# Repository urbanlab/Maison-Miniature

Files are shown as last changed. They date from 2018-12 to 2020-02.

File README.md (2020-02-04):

# Maison-Miniature

La Maison Miniature est un outil pour échanger avec les seniors sur la thématique du bien vivre chez soi dans le cadre d’ateliers collectifs de prévention. Cet objet physique facilite l’expression des bénéficiaires sur le sujet de l’adaptation du domicile. Il a été conçu et testé avec un ergothérapeute. Elle a été pensée pour les associations d’éducation et de prévention à la santé, les caisses de retraites, les mutuelles, et tous les professionnels de la prévention.

Maquette d’un habitat, elle reproduit à échelle réduite des espaces et du mobilier. Elle permet de mettre en scène différents aménagements, de reproduire les situations à risque et illustrer les bonnes pratiques. 

Les sources et les méthodologies du projet sont diffusées par la métropole de Lyon sous licenses ouvertes 
- AGPLV3 pour les plans
- CCBySA pour les documentations et plans

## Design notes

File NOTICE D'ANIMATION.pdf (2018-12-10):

# LA MAISON MINIATURE

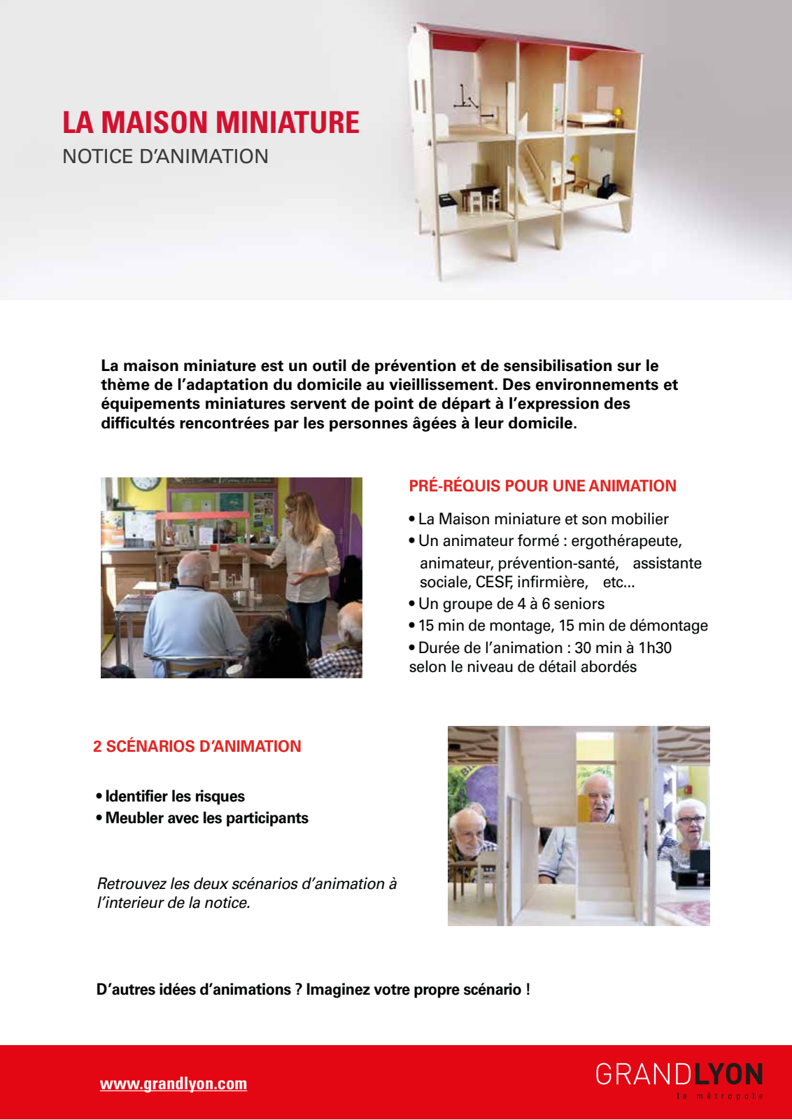
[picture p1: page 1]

### NOTICE D’ANIMATION

La maison miniature est un outil de prévention et de sensibilisation sur le thème de l’adaptation du domicile au vieillissement. Des environnements et équipements miniatures servent de point de départ à l’expression des difficultés rencontrées par les personnes âgées à leur domicile.

PRÉ-RÉQUIS POUR UNE ANIMATION

### 2 SCÉNARIOS D’ANIMATION

- La Maison miniature et son mobilier
- Un animateur formé : ergothérapeute, animateur, prévention-santé, assistante sociale, CESF, infirmière, etc...
- Un groupe de 4 à 6 seniors
- 15 min de montage, 15 min de démontage
- Durée de l’animation : 30 min à 1h30 selon le niveau de détail abordés
- Identifier les risques
- Meubler avec les participants

Retrouvez les deux scénarios d’animation à l’interieur de la notice.

D’autres idées d’animations ? Imaginez votre propre scénario !

www.grandlyon.com

# SCÉNARIO 1

### IDENTIFIER LES RISQUES

Avant le début de l’atelier, organiser les pièces de la maison avec le mobilier nécessaire en créant volontairement des zones à risque : tapis plissé, fils qui traînent, manque d’éclairage, encombrement, …

L’environnement de la maison sert alors de point de départ à l’expression des participants.

Échange pièces par pièce :

- L’animateur part d’une pièce (la cuisine par exemple) et invite les participants à identifier les éventuels dangers ou matériels inadaptés visibles dans la maison.

Partir de situations vécues :

- L’animateur invite les participants à partager leurs expériences sur des
situations | problématiques | qu’ils
peuvent rencontrer dans leur domicile.

### 2 possibilités :

Au fil de la discussion les participants et l’animateur échangent sur les solutions possibles.

L’animateur vient enrichir le dialogue avec des solutions techniques (conseils pratiques, aides techniques, aménagement entraînant des travaux) afin de rendre le logement sûr, confortable et sécurisé

Il modélise ses propos dans la maison grâce aux « éléments adaptés », afin de pouvoir visualiser l’environnement avec les solutions d’aménagements proposées.

1

2

4

5

6

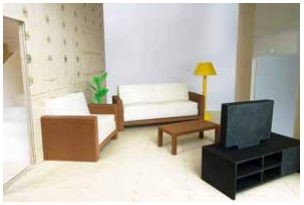
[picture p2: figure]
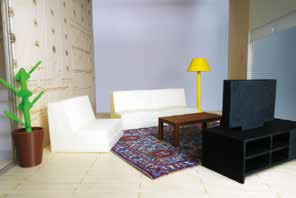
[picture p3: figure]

Avant : non adapté | Après: adapté

Notice technique Commencer la séance avec la maison vide de tout mobilier. Mettre à disposition des participants l’ensemble du mobilier disponible.

Demander aux participants d’aménager l’environnement comme ils le
souhaitent avec le mobilier mis à disposition

Plusieurs consignes sont possibles :

- Réaliser l’aménagement le plus adapté possible
- Réaliser l’aménagement le moins adapté possible
- Représenter les problématiques qu’ils rencontrent chez eux

Le temps d’aménagement permet à l’animateur de débuter les échanges avec les participants sur les éléments qui peuvent entraîner des difficultés dans la vie quotidienne ainsi que sur les éléments facilitateurs ou adaptés.

L’animateur vient enrichir le dialogue avec des solutions techniques (conseils pratiques, aides techniques, aménagement entraînant des travaux) afin de rendre le logement sûr, confortable et sécurisé

L’animateur modélise ses propos dans la maison grâce aux « éléments adaptés », afin de permettre de visualiser l’environnement avec les solutions d’aménagements proposées.

1

2

3

4

5

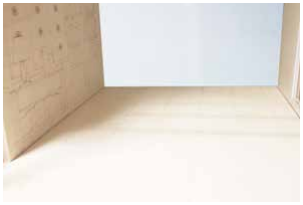
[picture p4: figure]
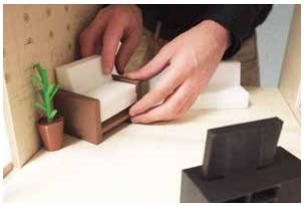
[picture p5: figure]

Avant : pièce vide | Pendant : pièce en cours de montage

# SCÉNARIO 2

### MEUBLER AVEC LES PARTICIPANTS

La maison miniature est un outil dont le développement
a été financé par la Conférence des financeurs de la prévention de la perte d’autonomie.

Elle a été imaginée avec l’expertise d’un ergothérapeute dans le contexte du projet Bien Vivre Chez Soi à la Métropole, mené par la Métropole de Lyon et Erasme.

La maquette a été conçue et développée par Youfactory
puis testée par la Métropole de Lyon et Erasme auprès de groupes de seniors.

Liens pratiques :
- https://www.grandlyon.com/
- https://www.erasme.org
- http://youfactory.co/
- https://www.cnsa.fr/
- Vidéo de présentation de l’outil : https://bit.ly/2FXnNia
- Notice de montage : https://bit.ly/2Q3kI54
- Page projet : https://www.erasme.org/La-Maison-Miniature-1
- Tous outils du projet Bien Vivre Chez Soi à La Métropole : https://www.erasme.org/#solidarite

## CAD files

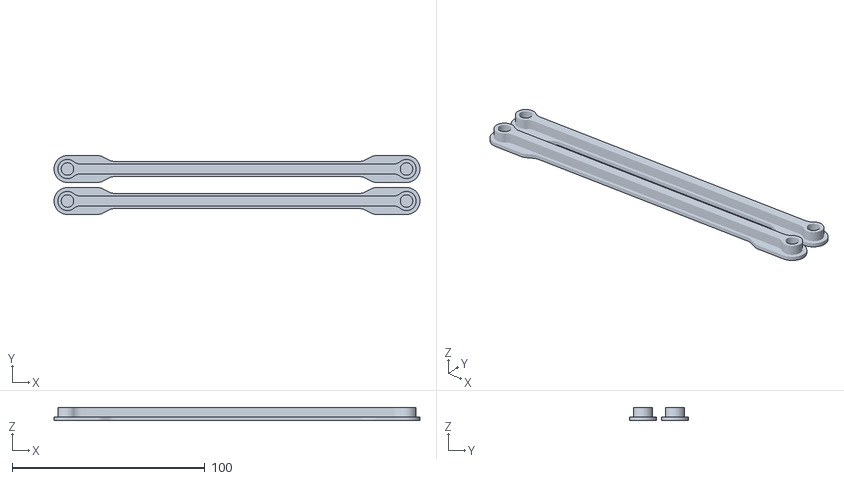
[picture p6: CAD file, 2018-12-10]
CAHIER DE PLANS/MOBILIER/IMPRESSION 3D/ESC-Main courantes.stl
190.0 x 30.6 x 7.00

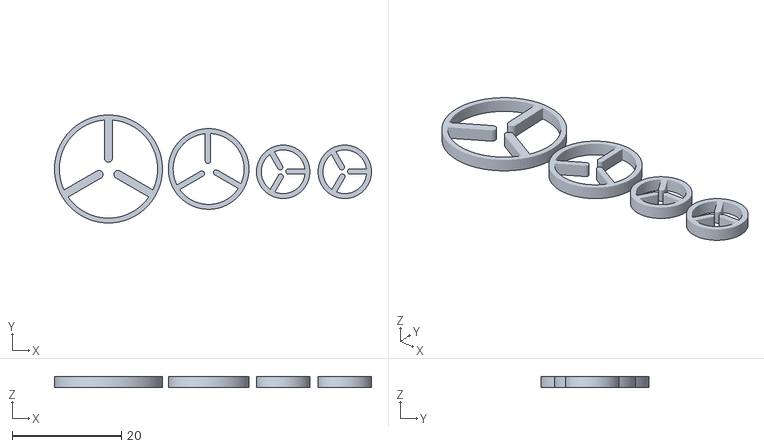
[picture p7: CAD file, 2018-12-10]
CAHIER DE PLANS/MOBILIER/IMPRESSION 3D/CUIS-Plaques gaz.stl
58.1 x 19.8 x 2.00

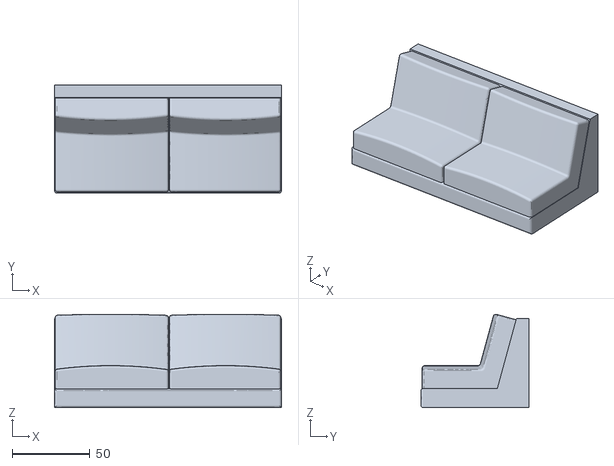
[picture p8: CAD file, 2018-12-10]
CAHIER DE PLANS/MOBILIER/IMPRESSION 3D/SAL-Canape assise.stl
146.0 x 69.7 x 60.1

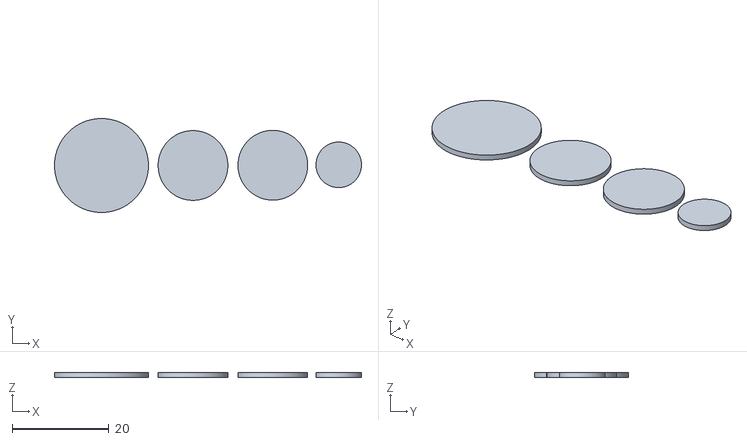
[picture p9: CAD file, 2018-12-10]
CAHIER DE PLANS/MOBILIER/IMPRESSION 3D/CUIS-Plaques vitro.stl
63.4 x 19.4 x 1

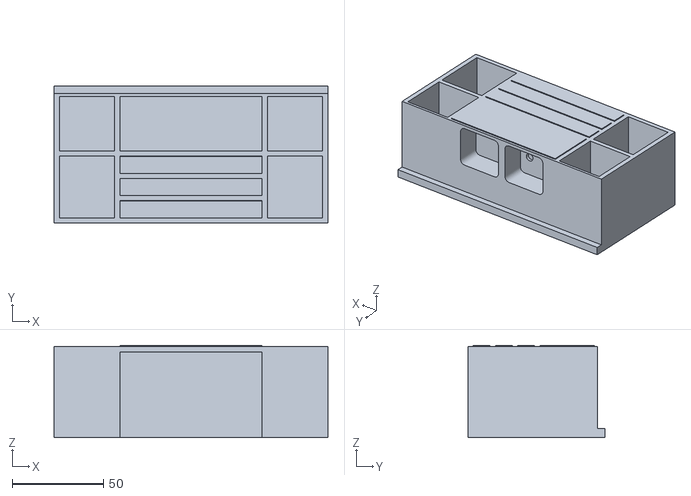
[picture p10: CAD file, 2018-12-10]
CAHIER DE PLANS/MOBILIER/IMPRESSION 3D/CUIS-Meuble evier Bot.stl
150.0 x 75.0 x 50.5

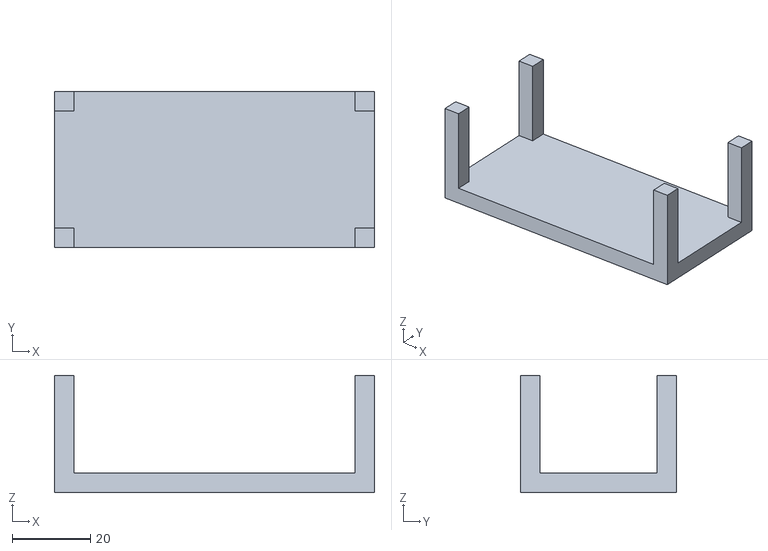
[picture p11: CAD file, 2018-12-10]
CAHIER DE PLANS/MOBILIER/IMPRESSION 3D/SAL-Table basse.stl
82.0 x 40.0 x 30.0

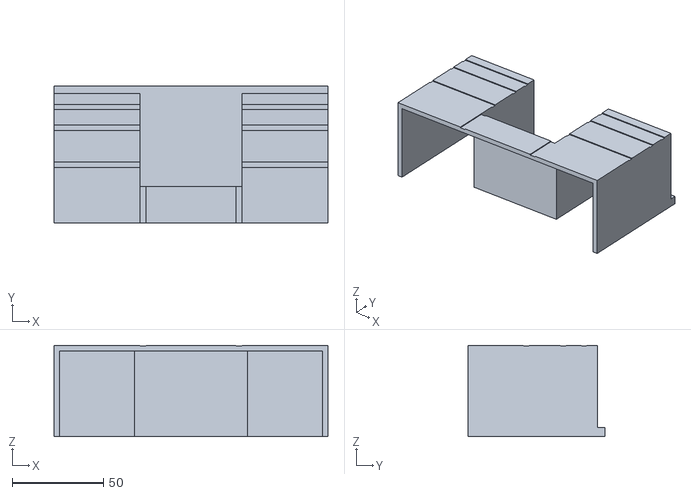
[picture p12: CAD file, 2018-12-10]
CAHIER DE PLANS/MOBILIER/IMPRESSION 3D/CUIS-Meuble cuisson Bot.stl
150.0 x 75.0 x 50.0

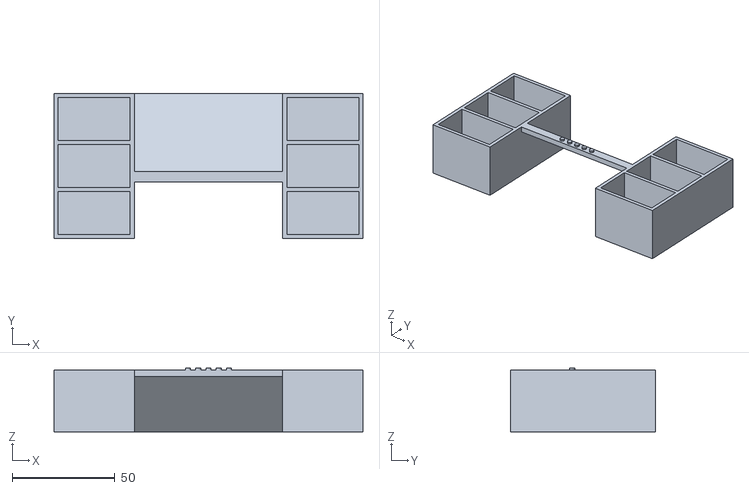
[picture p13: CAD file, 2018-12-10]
CAHIER DE PLANS/MOBILIER/IMPRESSION 3D/CUIS-Meuble cuisson Top.stl
150.0 x 70.5 x 31.0

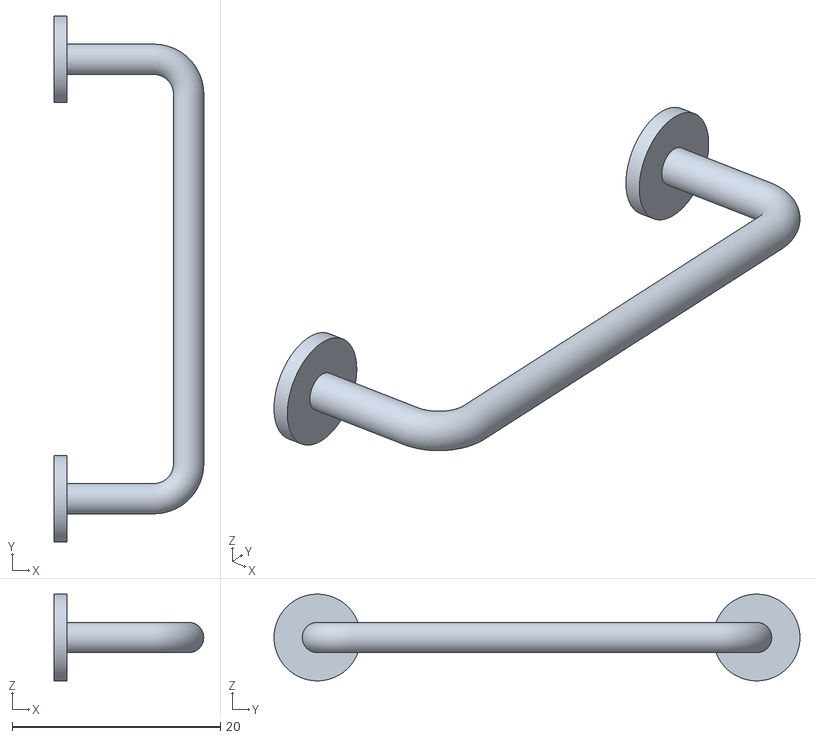
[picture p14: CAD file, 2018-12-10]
CAHIER DE PLANS/MOBILIER/IMPRESSION 3D/SDB-Douche petit barre.stl
14.4 x 50.5 x 8.33

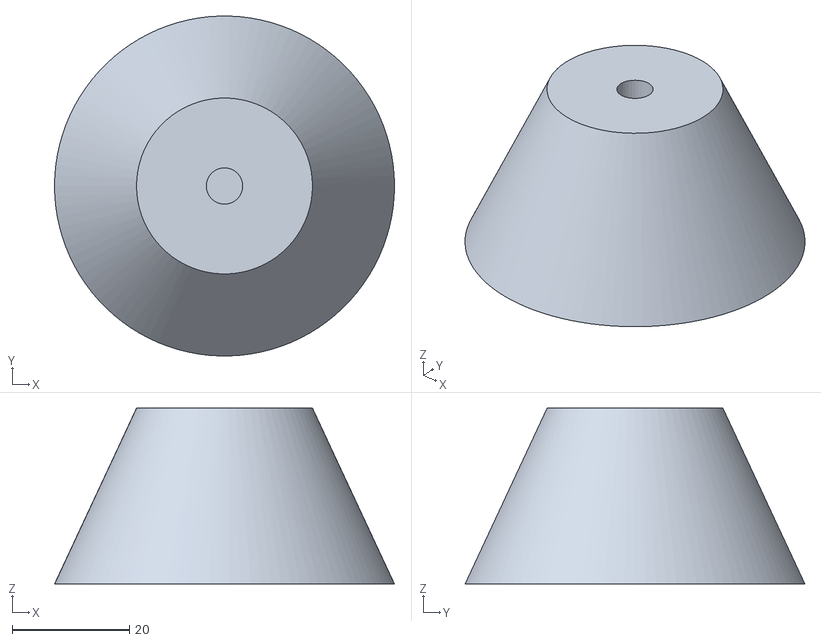
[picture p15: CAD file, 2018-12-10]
CAHIER DE PLANS/MOBILIER/IMPRESSION 3D/SAL-Plafonnier.stl
58.0 x 58.0 x 30.0

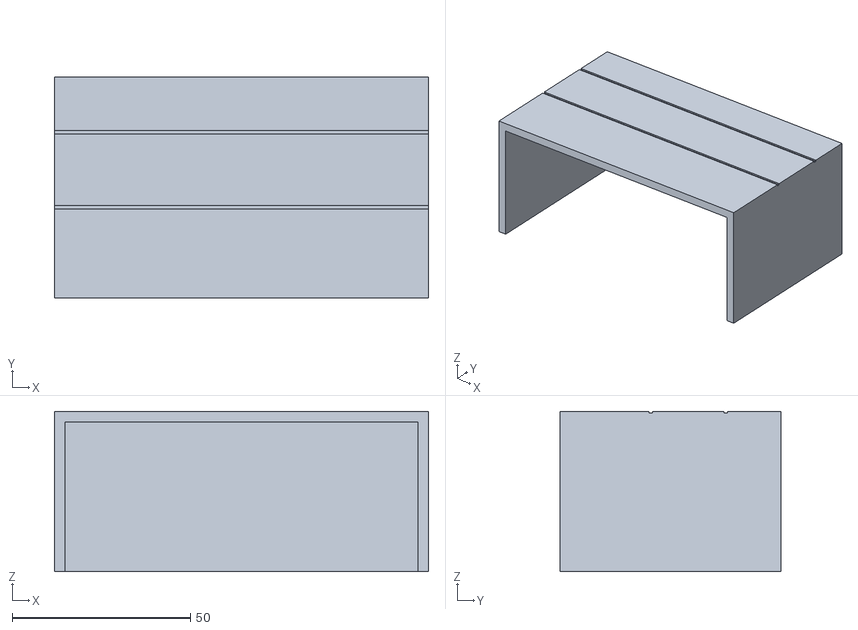
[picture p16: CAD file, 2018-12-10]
CAHIER DE PLANS/MOBILIER/IMPRESSION 3D/CHBRE-Commode.stl
105.0 x 62.0 x 45.0

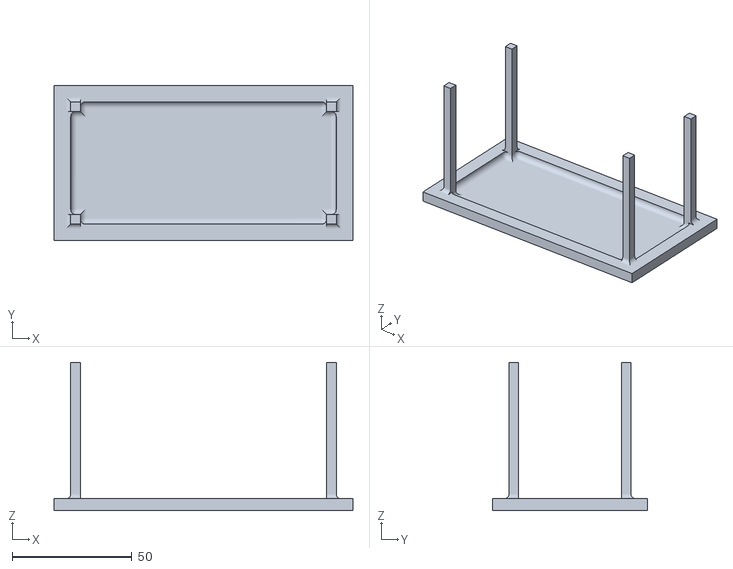
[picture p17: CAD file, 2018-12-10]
CAHIER DE PLANS/MOBILIER/IMPRESSION 3D/CUIS-Table Ö manger.stl
125.0 x 65.0 x 62.0

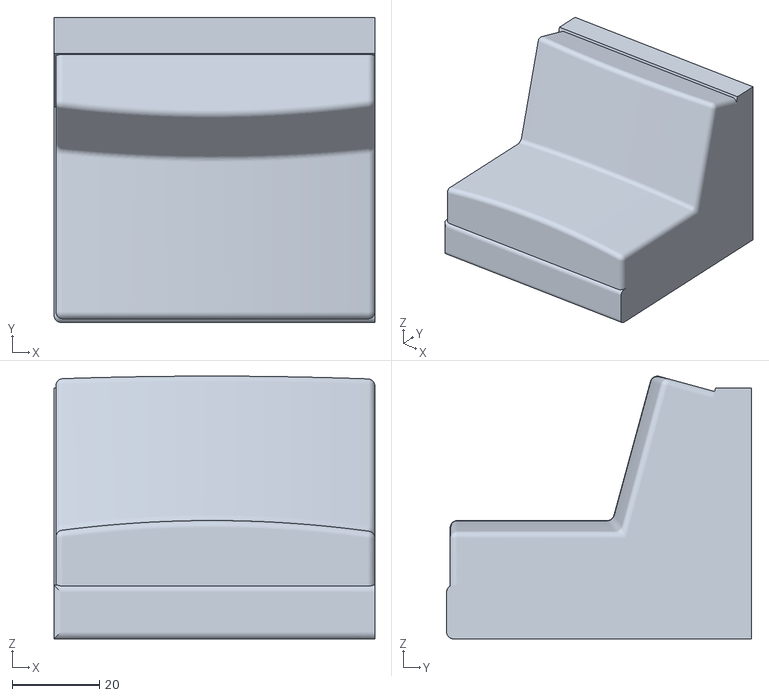
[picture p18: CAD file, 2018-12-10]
CAHIER DE PLANS/MOBILIER/IMPRESSION 3D/SAL-Fauteuil assise.stl
73.4 x 69.7 x 60.1

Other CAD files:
CAHIER DE PLANS/BOITE DE TRANSPORT/DECOUPE CNC/PLAN DE DECOUPE MOUSSE 15MM MANUEL.dwg
CAHIER DE PLANS/MURS ET PLANCHERS/CNC/FRAISAGE CNC MURS ET PLANCHERS.dwg
CAHIER DE PLANS/STRUCTURE ALUMINIUM/STRUCTURE ALUMINIUM.dwg
CAHIER DE PLANS/TOIT/CNC/DECOUPE TOIT.dwg
CAHIER DE PLANS/BOITE DE TRANSPORT/DECOUPE CNC/PLAN DE DECOUPE MOUSSE 25MM CNC.dwg
CAHIER DE PLANS/MOBILIER/IMPRESSION 3D/ATR-Cartons.stl
CAHIER DE PLANS/MOBILIER/IMPRESSION 3D/ATR-Plante.stl
CAHIER DE PLANS/MOBILIER/IMPRESSION 3D/ATR-Pot plante.stl
CAHIER DE PLANS/MOBILIER/IMPRESSION 3D/CHBRE-Lampe haute.stl
CAHIER DE PLANS/MOBILIER/IMPRESSION 3D/CHBRE-Matelas.stl
CAHIER DE PLANS/MOBILIER/IMPRESSION 3D/CHBRE-Sommier.stl
CAHIER DE PLANS/MOBILIER/IMPRESSION 3D/CHBRE-Table chevet X2.stl
CAHIER DE PLANS/MOBILIER/IMPRESSION 3D/CUIS-Bloc Vitro.stl
CAHIER DE PLANS/MOBILIER/IMPRESSION 3D/CUIS-Bloc gaziniäre.stl
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

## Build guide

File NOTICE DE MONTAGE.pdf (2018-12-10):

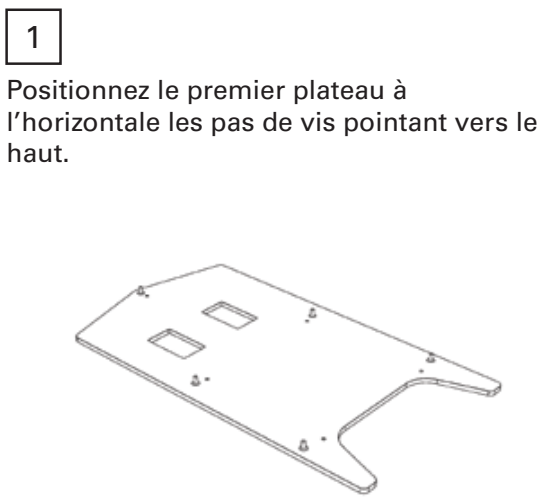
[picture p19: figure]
Positionnez le premier plateau à; haut.

l’horizontale les pas de vis pointant vers le

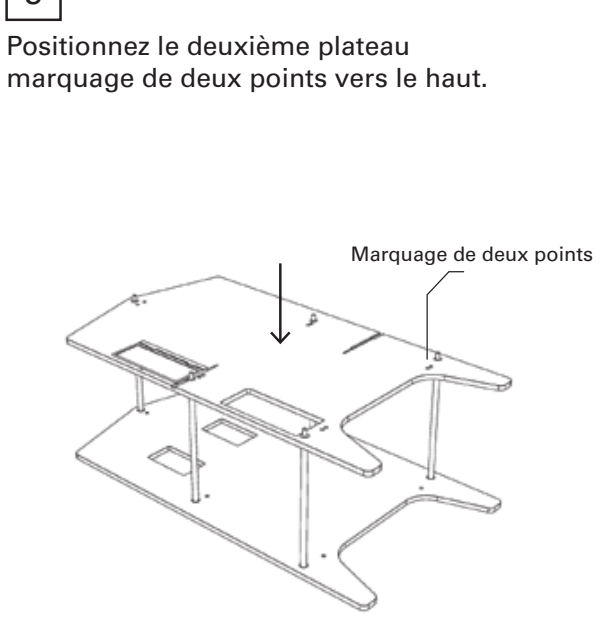
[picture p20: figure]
Positionnez le deuxième plateau marquage de deux points vers le haut.; Marquage de deux points

3

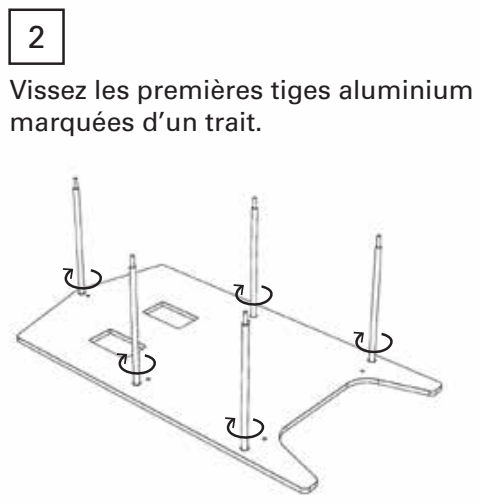
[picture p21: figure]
Vissez les premières tiges aluminium marquées d’un trait.
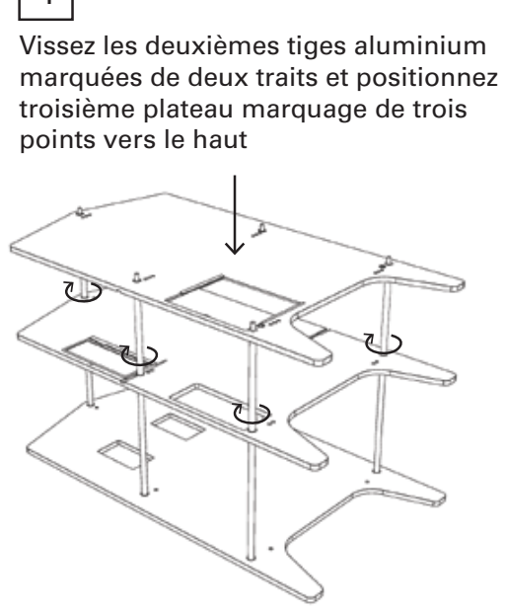
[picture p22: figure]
Vissez les deuxièmes tiges aluminium; troisième plateau marquage de trois points vers le haut

4

marquées de deux traits et positionnez le

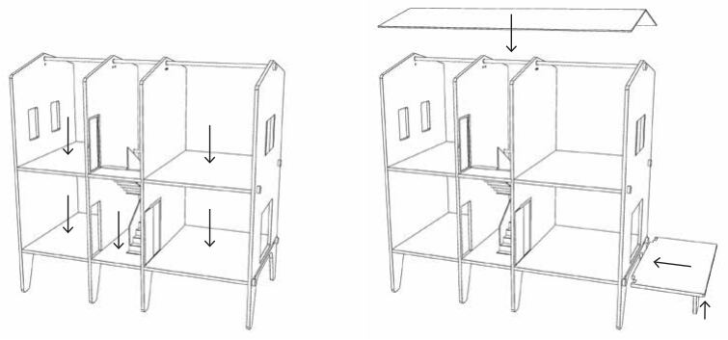
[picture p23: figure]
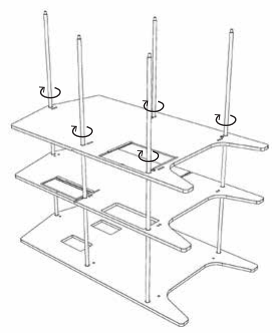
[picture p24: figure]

5

Vissez les troisièmes tiges aluminium marquées de troits traits.

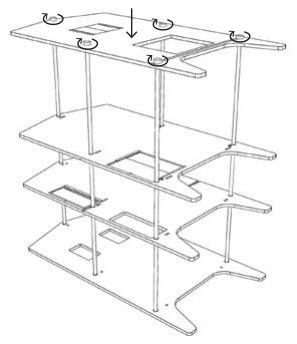
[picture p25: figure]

6

Positionnez le dernier plateau et vissez les cinq goupilles afin de solidariser l’ensemble.

7

8

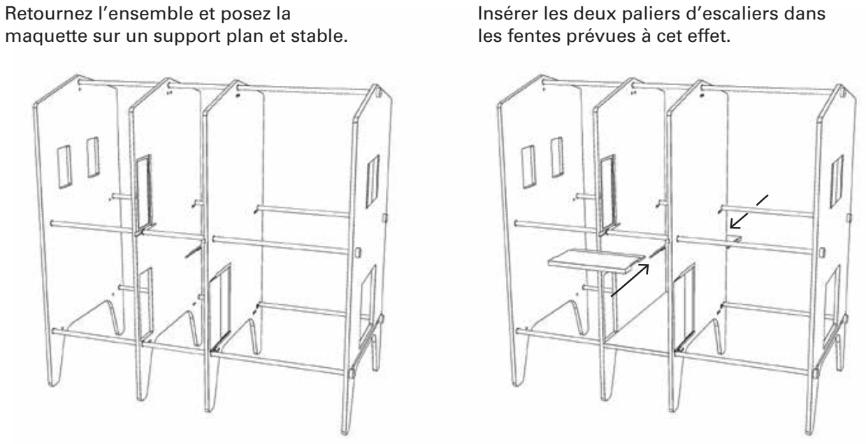
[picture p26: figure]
Retournez l’ensemble et posez la maquette sur un support plan et stable.; les fentes prévues à cet effet.

Insérer les deux paliers d’escaliers dans

9

Positionnez l’ensemble des planchers. Positionnez les deux travées d’escaliers. Elles reposent sur les deux paliers et sur le plancher central bas.

10

Positionnez le toit.
Fixez le socle du plancher de la terrasse et insérer l’ensemble dans la fente prévue sur le dernier panneau.

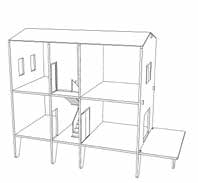
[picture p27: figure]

Votre maquette est prête à reçevoir son mobilier !

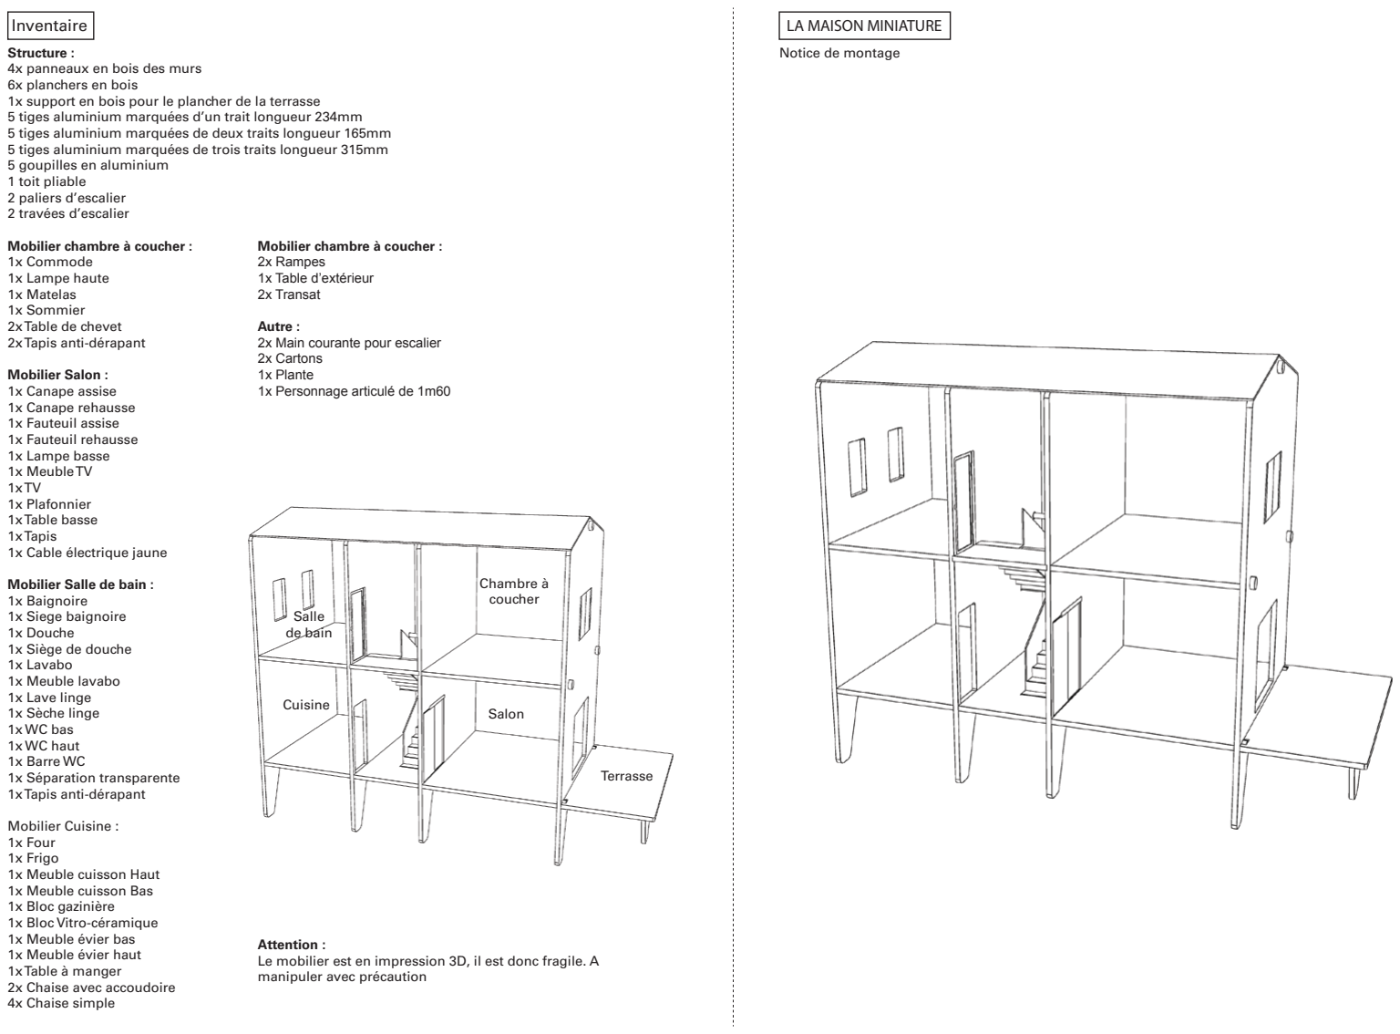
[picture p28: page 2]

Inventaire | LA MAISON MINIATURE

Structure :
4x panneaux en bois des murs
6x planchers en bois
1x support en bois pour le plancher de la terrasse
5 tiges aluminium marquées d’un trait longueur 234mm
5 tiges aluminium marquées de deux traits longueur 165mm 5 tiges aluminium marquées de trois traits longueur 315mm 5 goupilles en aluminium
1 toit pliable
2 paliers d’escalier
2 travées d’escalier

Mobilier chambre à coucher : 1x Commode
1x Lampe haute
1x Matelas
1x Sommier
2x Table de chevet
2x Tapis anti-dérapant

Mobilier Salon :
1x Canape assise
1x Canape rehausse
1x Fauteuil assise
1x Fauteuil rehausse
1x Lampe basse
1x Meuble TV
1x TV
1x Plafonnier
1x Table basse
1x Tapis
1x Cable électrique jaune

Mobilier Salle de bain :
1x Baignoire
1x Siege baignoire
1x Douche
1x Siège de douche
1x Lavabo
1x Meuble lavabo
1x Lave linge
1x Sèche linge
1x WC bas
1x WC haut
1x Barre WC
1x Séparation transparente 1x Tapis anti-dérapant

Mobilier Cuisine :
1x Four
1x Frigo
1x Meuble cuisson Haut
1x Meuble cuisson Bas
1x Bloc gazinière
1x Bloc Vitro-céramique
1x Meuble évier bas
1x Meuble évier haut
1x Table à manger
2x Chaise avec accoudoire
4x Chaise simple

Notice de montage

Mobilier chambre à coucher : 2x Rampes
1x Table d’extérieur
2x Transat

Autre :
2x Main courante pour escalier 2x Cartons
1x Plante
1x Personnage articulé de 1m60

Attention :
Le mobilier est en impression 3D, il est donc fragile. A manipuler avec précaution

Chambre à
coucher

Salon

Terrasse

Cuisine

Salle
de bain
